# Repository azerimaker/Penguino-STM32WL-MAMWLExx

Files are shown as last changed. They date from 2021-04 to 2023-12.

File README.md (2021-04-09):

# Penguino-STM32WL-MAMWLExx
This repo contains all the necessary design and fabrication files for the [Move Solution's MAMWLExx](https://www.hackster.io/move-solutions/design-a-lora-communication-board-based-on-mamwlexx-cbf25c) based Penguino STM32WL breakout board.

MAMWLExx is a very tiny low power radio module, which can be easily integrated into any PCB to enable it for wireless communication. It measures only 15x16mm and features 52 pins out of which 38 are multi-purpose GPIOs.

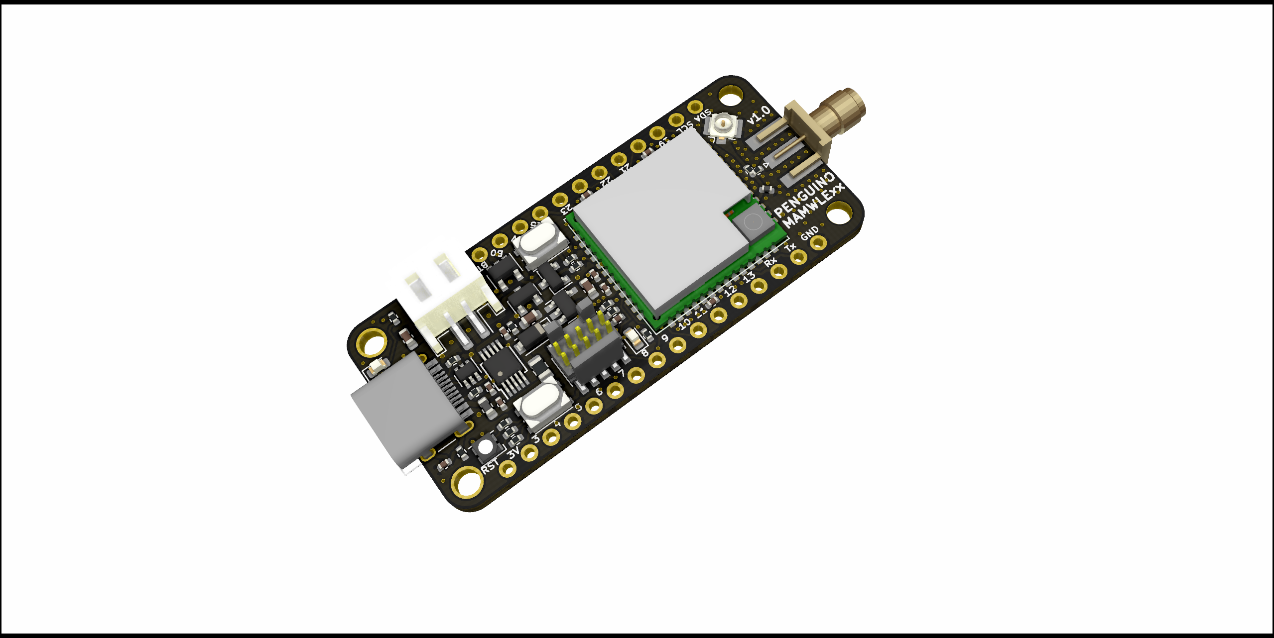
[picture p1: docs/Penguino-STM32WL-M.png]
Penguino-MAMWLExx


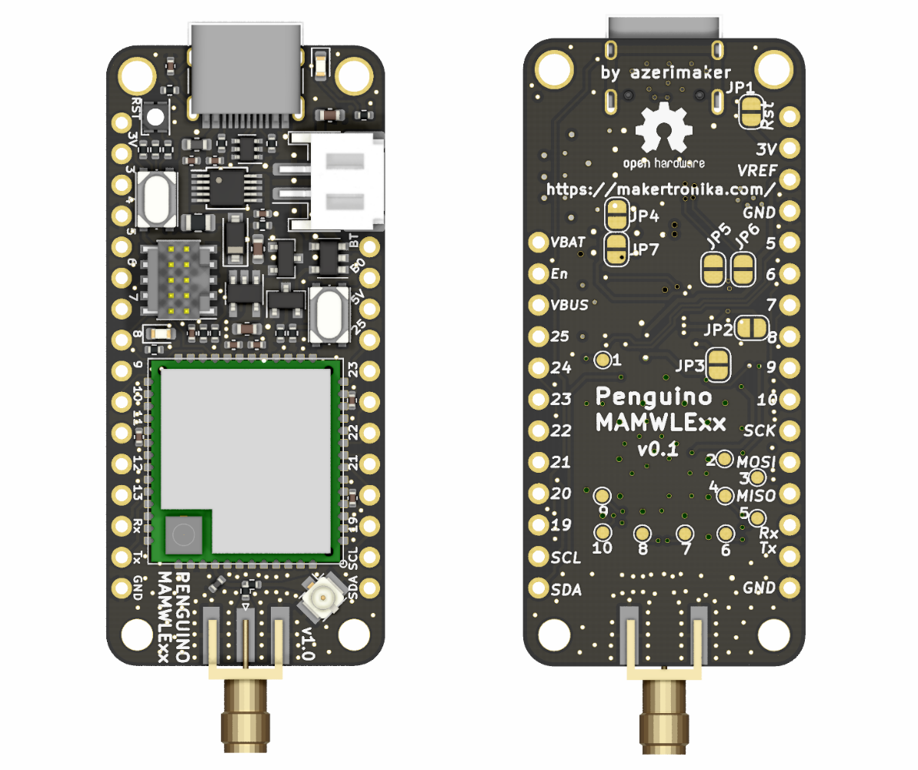
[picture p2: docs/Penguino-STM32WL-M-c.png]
Penguino-MAMWLExx-c


### Specs (SoC): 
- [STM32WLE5JC](https://www.st.com/en/microcontrollers-microprocessors/stm32wle5jc.html) Wireless SoC
- ARM Cortex M4 ultra-low-power MCU
- Integrated SX1262 RF transciever
- Frequency range: 150 MHz to 960 MHz.
- Modulation: LoRa®, (G)FSK, (G)MSK and BPSK
- Transmitter power: programmable up to +22 dBm 

### Specs ([MAMWLExx module](](https://www.hackster.io/move-solutions/mamwlexx-9f79eb))): 

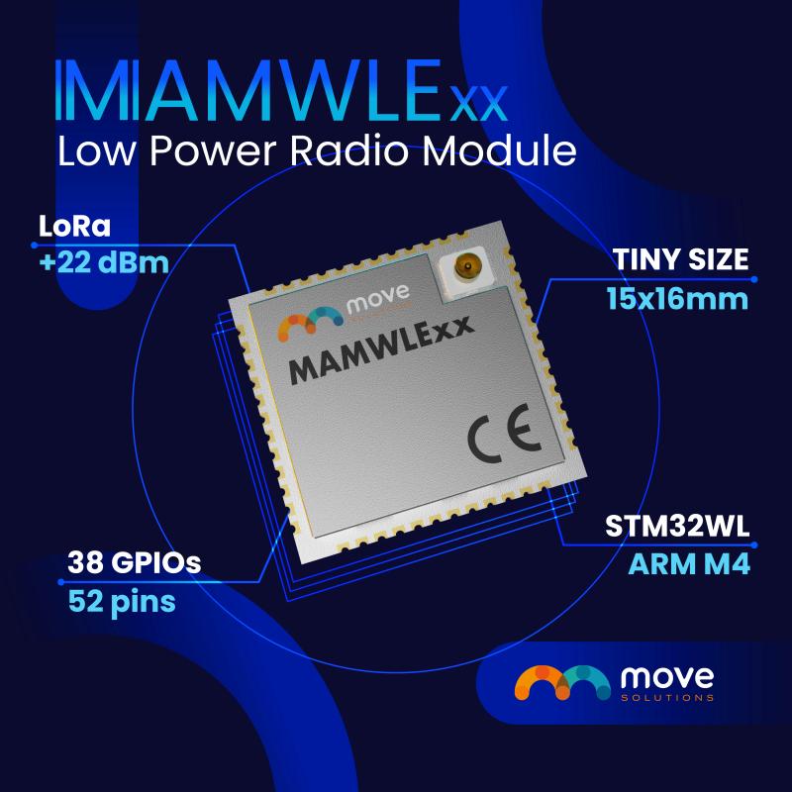
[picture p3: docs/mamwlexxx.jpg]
MAMWLExx


Board requirements:
- 4 layers, 1.6mm thickness
- 6mil trace/clearance
- 0.3mm drill

### Contact:
If you have any question or comments about the board please feel free to open an issue discussion or drop me a message at [@azerimaker](https://twitter.com/azerimaker). For any specific questions about the module please get in touch with [ Ferdinando Frediani ](https://www.linkedin.com/in/ferdinando-frediani-982807ab/) of Move Solutions, the creators of this awesome module. 

### License:
- Hardware license: CERN-OHL-S v2
- Software license: under MIT unless otherise indicated 
- Documentation license:  CC BY-SA 4.0 International.

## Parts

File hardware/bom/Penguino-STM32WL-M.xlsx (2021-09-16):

Date: | 5/13/2021 9:11:54 PM
Tool: | Eeschema (5.1.10)-1
Unique Component Count: |  | 32
Item | Ref | Qnty | Value | Footprint
1 | C1, C2, | 2 | 10nF | Capacitor_SMD:C_0402_1005Metric
2 | C3, C5, C6, | 3 | 10uF | Capacitor_SMD:C_0603_1608Metric
3 | C4, C7, C8, C9, C10, C12, C13, C14, | 8 | 100nF | Capacitor_SMD:C_0402_1005Metric
4 | D1, | 1 | CH_ORANGE | LED_SMD:LED_0603_1608Metric
5 | D2, | 1 | B5819W | Diode_SMD:D_SOD-123
6 | D3, | 1 | FM-B2020RGBA | LED_SMD:LED_Cree-PLCC4_2x2mm_CW
7 | D4, | 1 | PWR_BLUE | LED_SMD:LED_0603_1608Metric
8 | D5, | 1 | NUP2202 | Package_TO_SOT_SMD:SOT-363_SC-70-6
9 | D6, | 1 | PGB1010402 | Inductor_SMD:L_0402_1005Metric
10 | F1, | 1 | 0.75A | Fuse:Fuse_0805_2012Metric
11 | FB1, | 1 | PZ1608D221-1R0TF | Inductor_SMD:L_0603_1608Metric
12 | J1, | 1 | JST_PH | JST_PH_S2B-PH-SM4-TB_1x02-1MP_P2.00mm_Horizontal
13 | J2, | 1 | USB_C_Receptacle_USB2.0 | Connector_USB:USB_C_Receptacle_HRO_TYPE-C-31-M-12
14 | J3, | 1 | Conn_ARM_JTAG_SWD_10 | PinHeader_2x05_P1.27mm_Vertical_SMD
15 | J4, | 1 | U.FL-R-SMT-1 | Connector_Coaxial:U.FL_Hirose_U.FL-R-SMT-1_Vertical
16 | J5, | 1 | SMA-Edge-Mount | penguino_v1:SMA_J_P_X_ST_EM1_EdgeMount
17 | Q1, | 1 | SI2323DS | Package_TO_SOT_SMD:SOT-23
18 | R1, | 1 | 4K7 | Resistor_SMD:R_0402_1005Metric
19 | R2, R13, R14, | 3 | 1M | Resistor_SMD:R_0402_1005Metric
20 | R3, R5, R6, R7, | 4 | 1K5 | Resistor_SMD:R_0402_1005Metric
21 | R4, | 1 | 100K | Resistor_SMD:R_0402_1005Metric
22 | R8, | 1 | 1K2 | Resistor_SMD:R_0402_1005Metric
23 | R9, | 1 | 10K | Resistor_SMD:R_0402_1005Metric
24 | R11, R12, | 2 | 5K1 | Resistor_SMD:R_0402_1005Metric
25 | R15, R16, | 2 | 0R | Resistor_SMD:R_0402_1005Metric
26 | SW1, | 1 | RESET | penguino_v1:SW_Push_SKRPACE010
27 | SW2, | 1 | BOOT0 | penguino_v1:SW_Push_SKRPACE010
28 | U1, | 1 | MCP73831 | Package_TO_SOT_SMD:SOT-23-5
29 | U2, | 1 | RT9078-33GJ5 | Package_TO_SOT_SMD:TSOT-23-5
30 | U3, | 1 | TPS3839K33D | Package_TO_SOT_SMD:SOT-23
31 | U4, | 1 | CH340E | Package_SO:MSOP-10_3x3mm_P0.5mm
32 | U5, | 1 | MAMWLExx | stm32wl-lib-v1:stm32wl-mamwlexx-module-footprint_w_s_paste

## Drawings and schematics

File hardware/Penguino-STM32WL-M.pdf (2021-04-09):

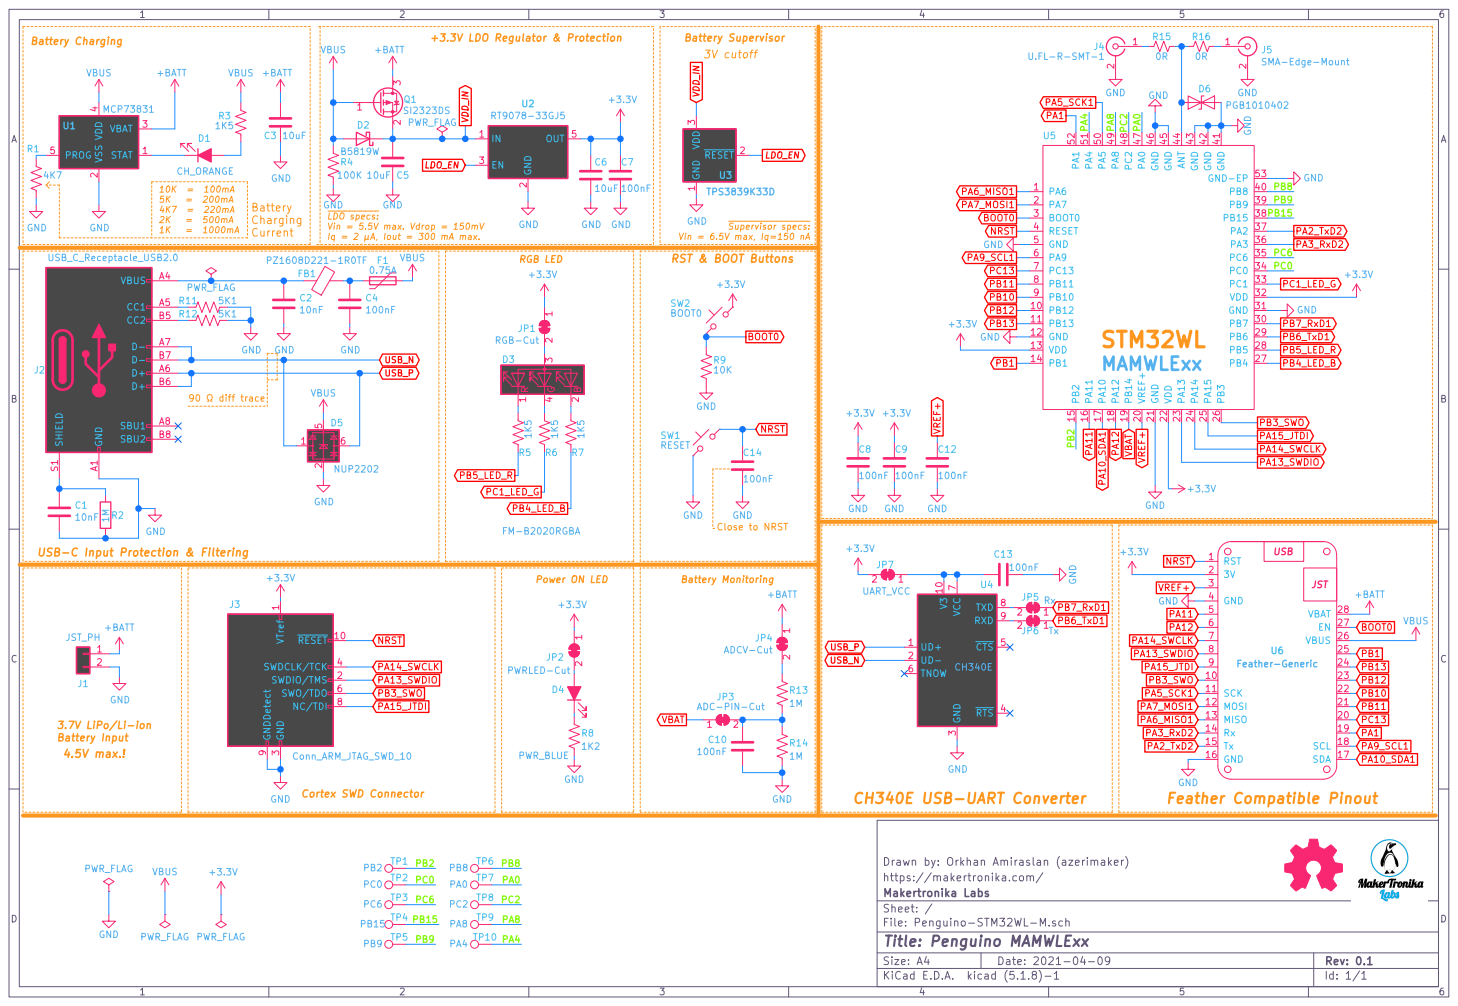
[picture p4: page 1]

2 EN 3 OUT 5 U2 RT9078-33GJ5 GND
J2 USB_C_Receptacle_USB2.0 GND
RGB LED USB-C Input Protection & Filtering

PB8 Supervisor specs: Vin = 6.5V max, Iq=150 nA Close to NRST RST & BOOT Buttons
+3.3V GND GND
VBUS GND

LDO specs: Vin = 5.5V max. Vdrop = 150mV

3 RTS 4 CTS 5 TNOW 6 VCC

3 SWDCLK/TCK 4 SWO/TDO 6 NC/TDI 8 GNDDetect 9

https://makertronika.com/
File: Penguino-STM32WL-M.sch Sheet: / Makertronika Labs

Id: 1/1 Title: Penguino MAMWLExx

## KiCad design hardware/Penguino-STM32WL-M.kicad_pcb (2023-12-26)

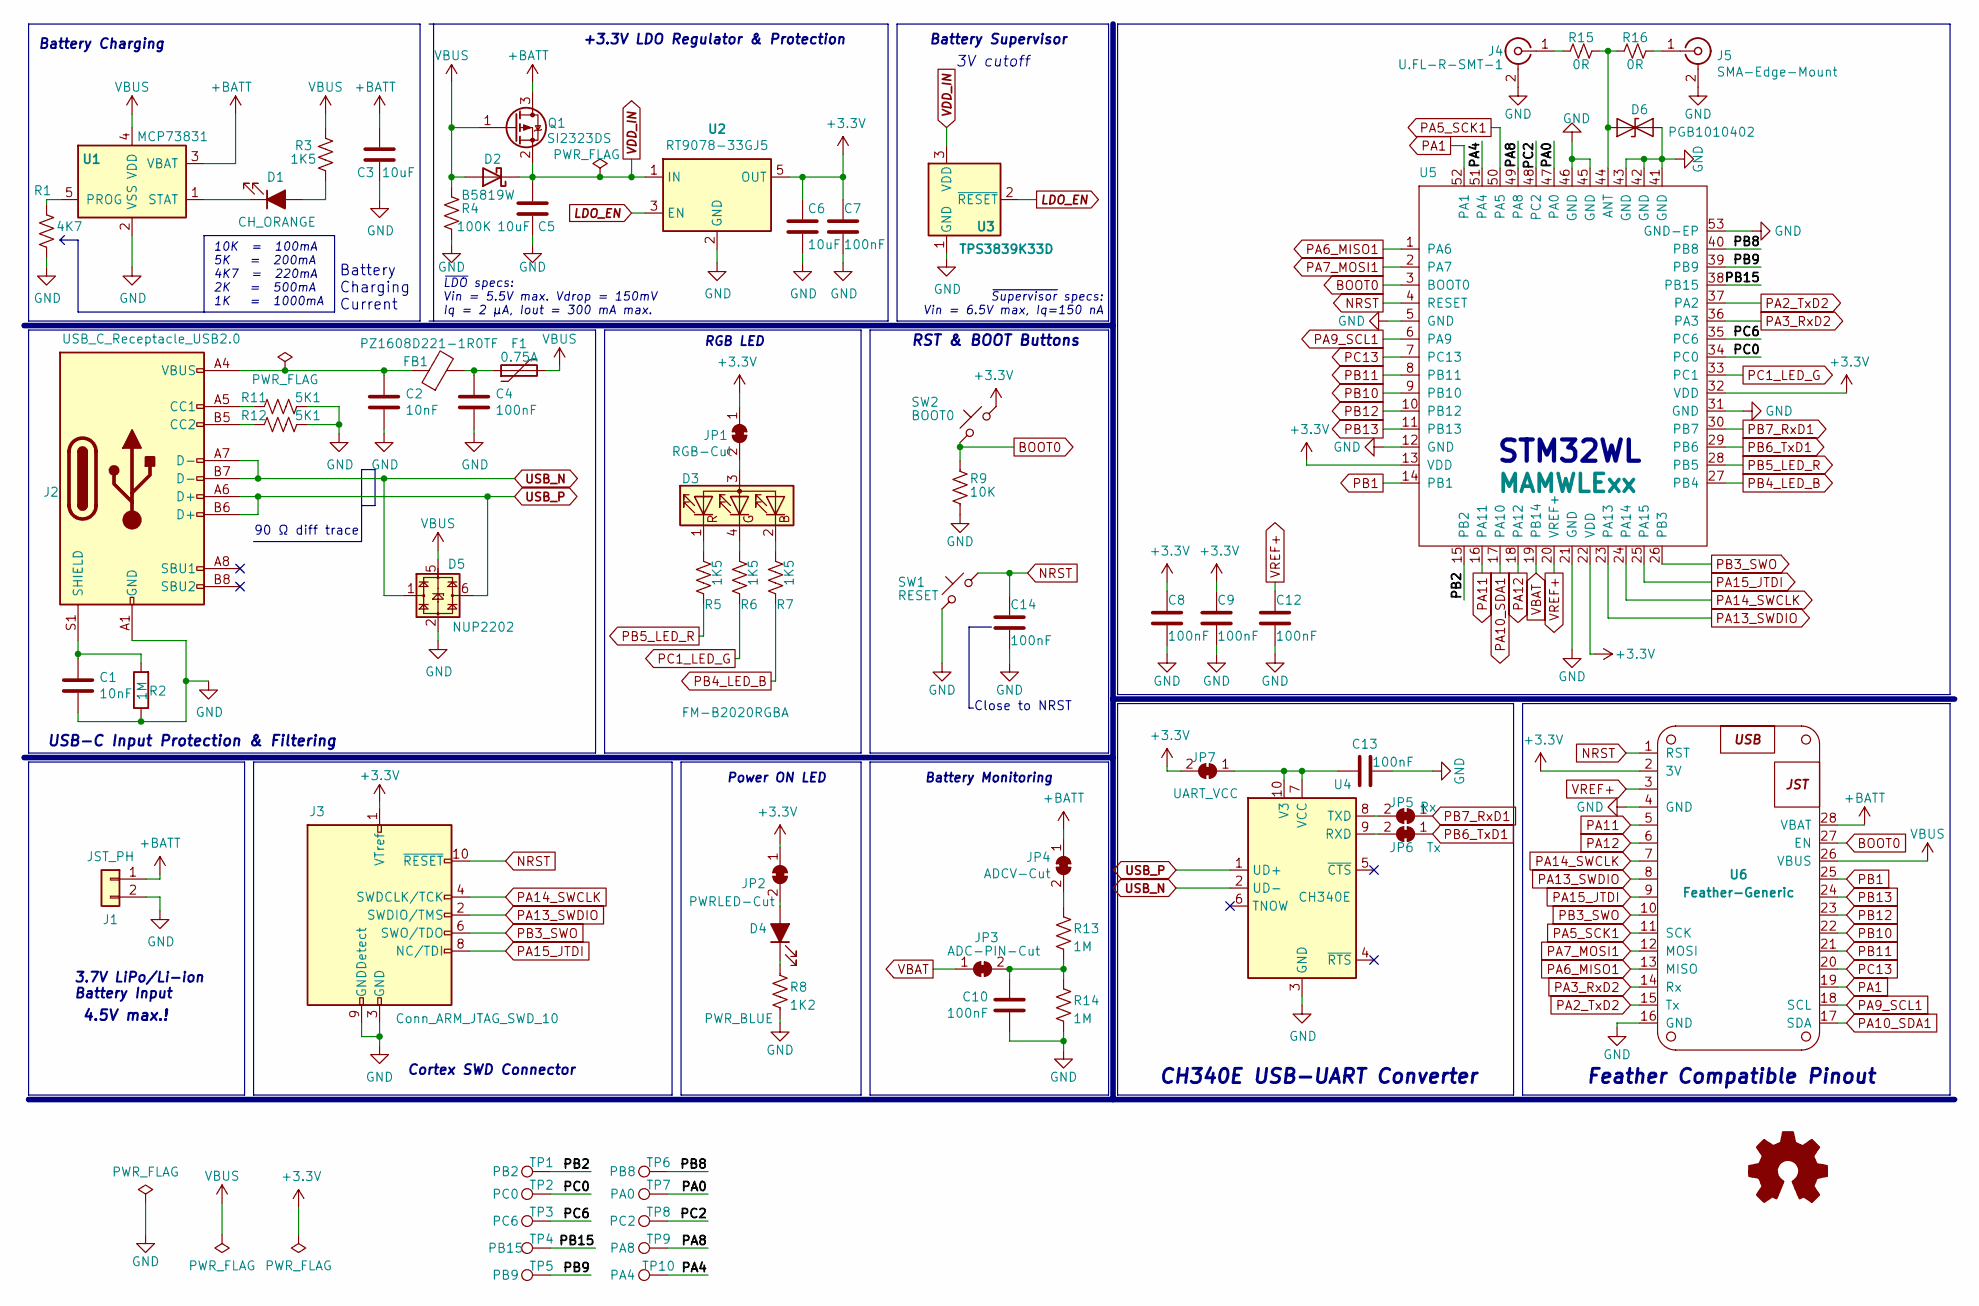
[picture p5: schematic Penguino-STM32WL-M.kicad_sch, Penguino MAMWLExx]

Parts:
C1, C2: 10nF; C_0402_1005Metric; MPN CC0402KRX7R9BB103; LCSC_Part# C57112
C3, C5, C6: 10uF; C_0603_1608Metric; MPN CC0603KRX5R6BB106; LCSC_Part# C19702
C4, C7, C8, C9, C12, C14: 100nF; C_0402_1005Metric; MPN GRM155R61A104KA01D; LCSC_Part# C14663
C10, C13: 100nF; C_0402_1005Metric; MPN GRM155R61A104KA01D; LCSC_Part# C1525
D1: CH_ORANGE; LED_0603_1608Metric; MPN 19-217-Y5C-AM1N1VY-3T; LCSC_Part# C375450
D2: B5819W; D_SOD-123; MPN B5819W; LCSC_Part# C8598
D3: FM-B2020RGBA; LED_Cree-PLCC4_2x2mm_CW; MPN FM-B2020RGBA-HG; LCSC_Part# C108793
D4: PWR_BLUE; LED_0603_1608Metric; MPN 19-217/BHC-ZL1M2RY/3T; LCSC_Part# C72041
D5: NUP2202; SOT-363_SC-70-6; MPN NUP2202; LCSC_Part# C502602
D6: PGB1010402; L_0402_1005Metric; MPN PGB1010402KR
F1: 0.75A; Fuse_0805_2012Metric; MPN SMD0805P075TF; LCSC_Part# C20979
FB1: PZ1608D221-1R0TF; L_0603_1608Metric; MPN PZ1608D221-1R0TF; LCSC_Part# C98286
J1: JST_PH; JST_PH_S2B-PH-SM4-TB_1x02-1MP_P2.00mm_Horizontal; MPN S2B-PH-SM4-TB(LF)(SN)
J2: USB_C_Receptacle_USB2.0; USB_C_Receptacle_HRO_TYPE-C-31-M-12; MPN TYPE-C-31-M-12
J3: Conn_ARM_JTAG_SWD_10; PinHeader_2x05_P1.27mm_Vertical_SMD; MPN 20021121-00010C4LF
J4: U.FL-R-SMT-1; U.FL_Hirose_U.FL-R-SMT-1_Vertical; MPN U.FL-R-SMT-1(80)
J5: SMA-Edge-Mount; SMA_J_P_X_ST_EM1_EdgeMount
JP1: RGB-Cut; SolderJumper-2_P1.3mm_Bridged_RoundedPad1.0x1.5mm
JP2: PWRLED-Cut; SolderJumper-2_P1.3mm_Bridged_RoundedPad1.0x1.5mm
JP3: ADC-PIN-Cut; SolderJumper-2_P1.3mm_Bridged_RoundedPad1.0x1.5mm
JP4: ADCV-Cut; SolderJumper-2_P1.3mm_Bridged_RoundedPad1.0x1.5mm
JP5: Rx; SolderJumper-2_P1.3mm_Bridged_RoundedPad1.0x1.5mm
JP6: Tx; SolderJumper-2_P1.3mm_Bridged_RoundedPad1.0x1.5mm
JP7: UART_VCC; SolderJumper-2_P1.3mm_Bridged_RoundedPad1.0x1.5mm
Q1: SI2323DS; SOT-23; MPN SI2323DS; LCSC_Part# C2593
R1: 4K7; R_0402_1005Metric; MPN RC0402JR-074K7L; LCSC_Part# C25900
R2, R13: 1M; R_0402_1005Metric; MPN RC0402JR-071ML; LCSC_Part# C26083
R3: 1K5; R_0402_1005Metric; MPN RC0402JR-071K5L
R4: 100K; R_0402_1005Metric; MPN RC0402JR-07100KL; LCSC_Part# C25741
R5, R6, R7: 1K5; R_0402_1005Metric; MPN RC0402JR-071K5L; LCSC_Part# C25862
R8: 1K2; R_0402_1005Metric; MPN 0402WGF1201TCE; LCSC_Part# C25862
R9: 10K; R_0402_1005Metric; MPN 0402WGF1201TCE; LCSC_Part# C25862
R11, R12: 5K1; R_0402_1005Metric; MPN RC0402FR-075K1L
R14: 1M; R_0402_1005Metric; MPN RC0402JR-071ML
R15, R16: 0R; R_0402_1005Metric; MPN RC0402JR-070RL
SW1: RESET; SW_Push_SKRPACE010; MPN SKRPACE010
SW2: BOOT0; SW_Push_SKRPACE010; MPN SKRPACE010
TP1: PB2; TestPoint_Pad_D1.0mm
TP2: PC0; TestPoint_Pad_D1.0mm
TP3: PC6; TestPoint_Pad_D1.0mm
TP4: PB15; TestPoint_Pad_D1.0mm
TP5: PB9; TestPoint_Pad_D1.0mm
TP6: PB8; TestPoint_Pad_D1.0mm
TP7: PA0; TestPoint_Pad_D1.0mm
TP8: PC2; TestPoint_Pad_D1.0mm
TP9: PA8; TestPoint_Pad_D1.0mm
TP10: PA4; TestPoint_Pad_D1.0mm
U1: MCP73831; SOT-23-5; MPN MCP73831T-2ACI/OT; LCSC_Part# C424093
U2: RT9078-33GJ5; TSOT-23-5; MPN RT9078-33GJ5; LCSC_Part# C110427
U3: TPS3839K33D; SOT-23; MPN TPS3839K33D; LCSC_Part# C9965
U4: CH340E; MSOP-10_3x3mm_P0.5mm; MPN CH340E; LCSC_Part# C99652
U5: MAMWLExx; stm32wl-mamwlexx-module-footprint_w_s_paste; MPN MAMWLExx
U6: Feather-Generic

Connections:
+3V3: C6.1, C7.1, C8.1, C9.1, J3.1 (VTref), JP1.1 (A), JP2.1 (A), JP7.2 (B), SW2.2, U2.5 (OUT), U5.13 (VDD), U5.22 (VDD), U5.32 (VDD), U6.2 (3V)
+BATT: C3.1, J1.1, JP4.1 (A), Q1.3 (D), U1.3 (VBAT), U6.28 (VBAT)
/PA0: TP7.1, U5.47 (PA0)
/PA4: TP10.1, U5.51 (PA4)
/PA8: TP9.1, U5.49 (PA8)
/PB2: TP1.1, U5.15 (PB2)
/PB8: TP6.1, U5.40 (PB8)
/PB9: TP5.1, U5.39 (PB9)
/PB15: TP4.1, U5.38 (PB15)
/PC0: TP2.1, U5.34 (PC0)
/PC2: TP8.1, U5.48 (PC2)
/PC6: TP3.1, U5.35 (PC6)
BOOT0: R9.1, SW2.1, U5.3 (BOOT0), U6.27 (EN)
GND: C1.1, C2.2, C3.2, C4.2, C5.2, C6.2, C7.2, C8.2, C9.2, C10.1, C12.2, C13.2, C14.2, D5.2, D6.1 (A1), J1.2, J2.A1 (GND), J2.A12 (GND), J2.B1 (GND), J2.B12 (GND), J3.3 (GND), J3.5 (GND), J3.9 (GNDDetect), J4.2 (Ext), J5.2 (Ext), R1.2, R2.1, R4.2, R8.2, R9.2, R11.1, R12.1, R14.2, SW1.1, U1.2 (VSS), U2.2 (GND), U3.1 (GND), U4.3 (GND), U5.5 (GND), U5.12 (GND), U5.21 (GND), U5.31 (GND), U5.41 (GND), U5.42 (GND), U5.43 (GND), U5.45 (GND), U5.46 (GND), U5.53 (GND-EP), U5.54 (GND-EP), U5.55 (GND-EP), U5.56 (GND-EP), U5.57 (GND-EP), U5.58 (GND-EP), U5.59 (GND-EP), U5.60 (GND-EP), U5.61 (GND-EP), U5.62 (GND-EP), U5.63 (GND-EP), U5.64 (GND-EP), U5.65 (GND-EP), U5.66 (GND-EP), U6.4 (GND), U6.16 (GND)
LDO_EN: U2.3 (EN), U3.2 (~RESET)
NRST: C14.1, J3.10 (~RESET), SW1.2, U5.4 (RESET), U6.1 (RST)
unnamed: C1.2, J2.S1 (SHIELD), R2.2
unnamed: C2.1, FB1.1, J2.A4 (VBUS), J2.A9 (VBUS), J2.B4 (VBUS), J2.B9 (VBUS)
unnamed: C4.1, F1.1, FB1.2
unnamed: C10.2, JP3.2 (B), R13.2, R14.1
unnamed: C13.1, JP7.1 (A), U4.7 (VCC), U4.10 (V3)
unnamed: D1.1 (K), U1.1 (STAT)
unnamed: D1.2 (A), R3.2
unnamed: D3.1 (RK), R5.1
unnamed: D3.2 (BK), R7.1
unnamed: D3.3 (A), JP1.2 (B)
unnamed: D3.4 (GK), R6.1
unnamed: D4.1 (K), R8.1
unnamed: D4.2 (A), JP2.2 (B)
unnamed: D6.2 (A2), R15.1, R16.2, U5.44 (ANT)
unnamed: J2.A5 (CC1), R11.2
unnamed: J2.B5 (CC2), R12.2
unnamed: J4.1 (In), R15.2
unnamed: J5.1 (In), R16.1
unnamed: JP4.2 (B), R13.1
unnamed: JP5.2 (B), U4.8 (TXD)
unnamed: JP6.2 (B), U4.9 (RXD)
unnamed: R1.1, U1.5 (PROG)
PA1: U5.52 (PA1), U6.19
PA2_TxD2: U5.37 (PA2), U6.15 (Tx)
PA3_RxD2: U5.36 (PA3), U6.14 (Rx)
PA5_SCK1: U5.50 (PA5), U6.11 (SCK)
PA6_MISO1: U5.1 (PA6), U6.13 (MISO)
PA7_MOSI1: U5.2 (PA7), U6.12 (MOSI)
PA9_SCL1: U5.6 (PA9), U6.18 (SCL)
PA10_SDA1: U5.17 (PA10), U6.17 (SDA)
PA11: U5.16 (PA11), U6.5
PA12: U5.18 (PA12), U6.6
PA13_SWDIO: J3.2 (SWDIO/TMS), U5.23 (PA13), U6.8
PA14_SWCLK: J3.4 (SWDCLK/TCK), U5.24 (PA14), U6.7
PA15_JTDI: J3.8 (NC/TDI), U5.25 (PA15), U6.9
PB1: U5.14 (PB1), U6.25
PB3_SWO: J3.6 (SWO/TDO), U5.26 (PB3), U6.10
PB4_LED_B: R7.2, U5.27 (PB4)
PB5_LED_R: R5.2, U5.28 (PB5)
PB6_TxD1: JP6.1 (A), U5.29 (PB6)
PB7_RxD1: JP5.1 (A), U5.30 (PB7)
PB10: U5.9 (PB10), U6.22
PB11: U5.8 (PB11), U6.21
PB12: U5.10 (PB12), U6.23
PB13: U5.11 (PB13), U6.24
PC1_LED_G: R6.2, U5.33 (PC1)
PC13: U5.7 (PC13), U6.20
USB_N: D5.1, J2.A7 (D-), J2.B7 (D-), U4.2 (UD-)
USB_P: D5.6, J2.A6 (D+), J2.B6 (D+), U4.1 (UD+)
VBAT: JP3.1 (A), U5.19 (PB14)
VBUS: D2.2 (A), D5.5, F1.2, Q1.1 (G), R3.1, R4.1, U1.4 (VDD), U6.26 (VBUS)
VDD_IN: C5.1, D2.1 (K), Q1.2 (S), U2.1 (IN), U3.3 (VDD)
VREF+: C12.1, U5.20 (VREF+), U6.3

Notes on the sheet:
Battery Charging Current
Power ON LED
Cortex SWD Connector
Battery Monitoring
~{LDO} specs: Vin = 5.5V max. Vdrop = 150mV Iq = 2 μA, Iout = 300 mA max.
90 Ω diff trace
Battery Supervisor
10K = 100mA 5K = 200mA 4K7 = 220mA 2K = 500mA 1K = 1000mA
3V cutoff
USB-C Input Protection & Filtering
4.5V max.!
RGB LED
CH340E USB-UART Converter
STM32WL
Feather Compatible Pinout
3.7V LiPo/Li-ion Battery Input
RST & BOOT Buttons
+3.3V LDO Regulator & Protection
Battery Charging
~{Supervisor} specs: Vin = 6.5V max, Iq=150 nA
Close to NRST

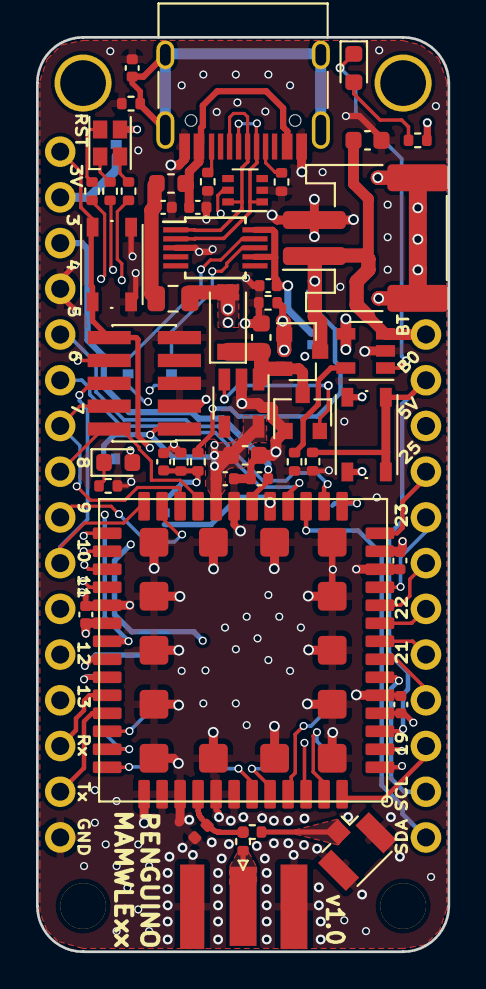
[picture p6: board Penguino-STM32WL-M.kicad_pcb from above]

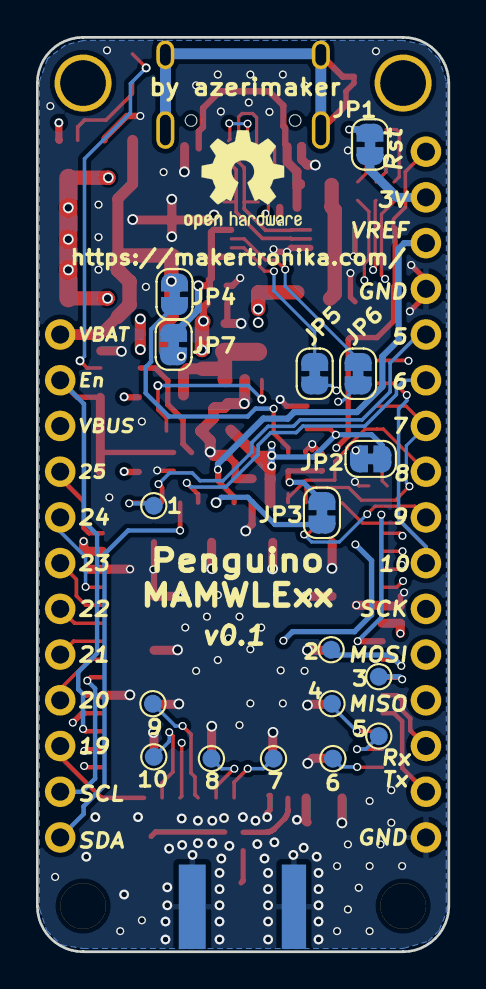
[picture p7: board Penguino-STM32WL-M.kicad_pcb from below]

Board: 4 copper layers, 22.9 x 50.8 mm, 67 parts (17 on the bottom side), 69 nets.

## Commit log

2021-04-09 sch, pcb, doc: Add initial version of the design
    [Penguino-STM32WL-M-B_Mask.gbs, Penguino-STM32WL-M-B_Paste.gbp, Penguino-STM32WL-M-B_SilkS.gbo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]
2021-04-09 lib: Add iBOM file
    [Penguino-STM32WL-M.kicad_pcb, Penguino-STM32WL-M.sch]
2021-09-16 add: STM32CubeIDE Project Examples
    RGB Toggle and LoRaWAN example.
    LoRaWAN end node example uses USART2 on PA2 and PA3 (Feather pins 14 and 15)
    add: BOM list
    [Penguino-STM32WL-M.xlsx]
2023-12-26 hw, fw: Examples added, KiCAD version upgraded
    [Penguino-STM32WL-M.kicad_pcb, Penguino-STM32WL-M.kicad_sch, Penguino-STM32WL-M.sch]
